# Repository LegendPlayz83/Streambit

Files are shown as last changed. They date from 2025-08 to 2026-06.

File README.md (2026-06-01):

# Streambit

This is my 65% Keyboard, which I made from scratch with some help. It is named Streambit.<br>

Physical view:


Full-assembled

<br>
A special thanks to Kai, Anay, Mohid, and Souptik, and a big thanks to Alex, who is helping me improve my projects. 💓

# Inspiration
I've always wanted to build a keyboard, and Blueprint gave me the perfect opportunity for this

# Challenges
This was the first time using some new libraries. There were not many big issues, just usage problems which were resolved on Slack <a href="hackclub.slack.com/archives/C0948RT0C1M">Grounded</a>.
<br>
It was sad getting your keyboard rejected. The spirit of getting it approved on the first try is something else.

# Specifications

# Keyboard PCB – Bill of Materials (BOM)

| Component | Quantity | Unit Price | Total |
|---|---|---|---|
| [**TTC Silent Red V3 MX Mechanical Switches**](https://stackskb.com/store/ttc-silent-red-v3-switch/) | 64 | $0.45 | $28.80 |
| [**1N4148 Switching Diodes**](https://amzn.in/d/02ax8rq9) | 100 | $0.0206 | $2.06 |
| [**Cherry MX Plate Mount Stabilizers (2U)**](https://stackskb.com/store/genuine-cherry-mx-plate-mount-stabilizers-2u/) | 4 | $1.30 | $5.20 |
| [**Durock Smokey Screw-In Stabilizers V2 (4+1 w/ 6.25u spacebar)**](https://stackskb.com/store/durock-smokey-screw-in-stabilizers-v2/) | 1 | $18.58 | $18.58 |
| [**EC11 Rotary Encoder with Switch**](https://www.flyrobo.in/15mm-ec11-rotary-encoder-with-switch-digital-potentiometer) | 1 | $0.68 | $0.68 |
| **SK6812 MINI LEDs** | 4  | $2.95 | $2.95 |
| [**Raspberry Pi Zero W**](https://amzn.in/d/4E8fnHk) | 1 | $10.00 | $10.00 |
| [**Iceberg Japanese XDA PBT Keycaps**](https://curiositycaps.in/products/iceberg-japanese-xda-pbt-keycaps-1) | 1 | $25.00 | $25.00 |
| [**Custom PCB (JLCPCB)**](https://jlcpcb.com/) | 1 | $48.86 | $48.86 |
| **Case (From printing-legion)** | 1 | $5.00 | $5.00 |
---

**Grand Total: $147.13**<br>
Others:
<ul>
<li>KMK Firmware
<li>Top Case.stl
</ul>

<h3>Schematic-</h3>
Screenshot 2025-07-25 at 6 26 07 PM

<h3>PCB</h3>
pcb

<h3>PCB in 3D view</h3>
3d view

<h3>Case</h3>
case
psst: two keys were placed wrongly dont mind :)

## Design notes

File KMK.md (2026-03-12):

## Flashing nd Configuring the Keyboard

Steps to install the firmware and configure the keyboard:-

### 1. Downloading the Repository
Download or clone this repository to your computer.
https://github.com/LegendPlayz83/Streambit.git

### 2. Enter Boot Mode on the Pico
1. Unplug the Raspberry Pi Pico from your computer.
2. Hold down the **BOOTSEL** button on the Pico.
3. While holding the button, plug the Pico into your computer using a USB cable.
4. The computer will detect a new drive, namely **RPI-RP2**.

### 3. Flash the Firmware
1. Download the `.uf2` firmware file from this repo.
2. Drag and drop the file onto the **RPI-RP2** drive.

Once the file finishes copying, the Pico will reboot automatically.

### 4. Install KMK Files
After rebooting, the Pico will appear as a new drive (usually named **CIRCUITPY**).

Copy the KMK firmware files from this repository onto the Pico if they are not already included.

### 5. Configure the Keymap
The keyboard layout can be customised in the `code.py` (or `keymap.py`) file.

Open the file in a text editor nd edit the keymap section to match the layout you want.  
After saving the file, the keyboard will automatically reload with the new configuration.

### 6. Test the Keyboard
Unplug and reconnect the keyboard, open a text editor, and press some keys to make sure everything works.

<h1>KABOOM!</h1>
ITS DONE!!!

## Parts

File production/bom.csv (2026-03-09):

Name | Quantity | Cost | Link
TTC Silent Red V3 | 70 | $28.80 | https://stackskb.com/store/ttc-silent-red-v3-switch/
Durock Smokey Screw-In Stabilizers V2 (4+1 w/ 6.25u spacebar) | 1 | $18.58 | https://stackskb.com/store/durock-smokey-screw-in-stabilizers-v2/
EC11 Rotary Encoder with Switch | 1 | $0.68 | https://www.flyrobo.in/15mm-ec11-rotary-encoder-with-switch-digital-potentiometer
Cherry MX Plate Mount Stabilizers (2U) | 4 | $5.20 | https://stackskb.com/store/genuine-cherry-mx-plate-mount-stabilizers-2u/
Iceberg Japanese XDA PBT Keycaps | 1 | $25.00 | https://curiositycaps.in/products/iceberg-japanese-xda-pbt-keycaps-1
Diode 1N4148 Through - Hole | 100 | $2.06 | https://www.amazon.in/dp/B084ZP5BJ3?ref_=cm_sw_r_cp_ud_dp_YPW3WFYTE31QA18570D1&_encoding=UTF8&psc=1
SK6812 LEDs | 4 | $2.95 | Local store
PCB - (Black Color) | 5 | $48.86 | https://jlcpcb.com/
Raspberry Pi Pico | 1 | $10.00 | https://amzn.in/d/4E8fnHk
Case- top,mid,bot | 1 | $5.00 | Printing Legion transport charges

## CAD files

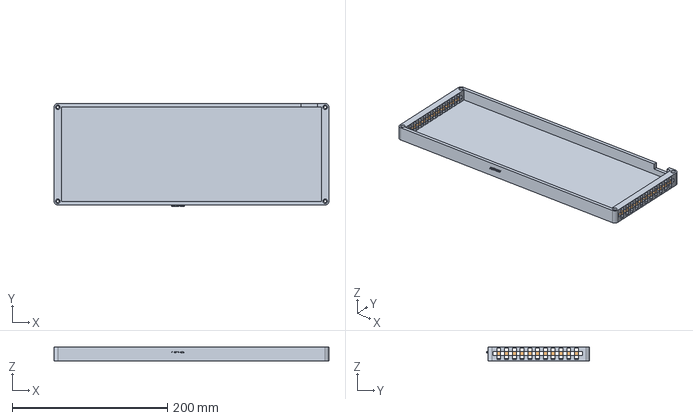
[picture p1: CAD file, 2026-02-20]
cad/Streambit Case.step
354.0 x 133.0 x 18.0 mm

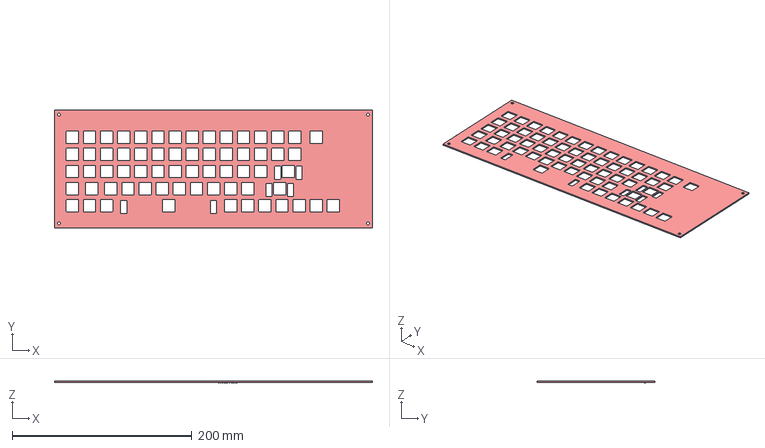
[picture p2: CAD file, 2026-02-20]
cad/Bitstream cover.step
354.0 x 131.0 x 1.70 mm

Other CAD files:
production/Streambit_Top.stl

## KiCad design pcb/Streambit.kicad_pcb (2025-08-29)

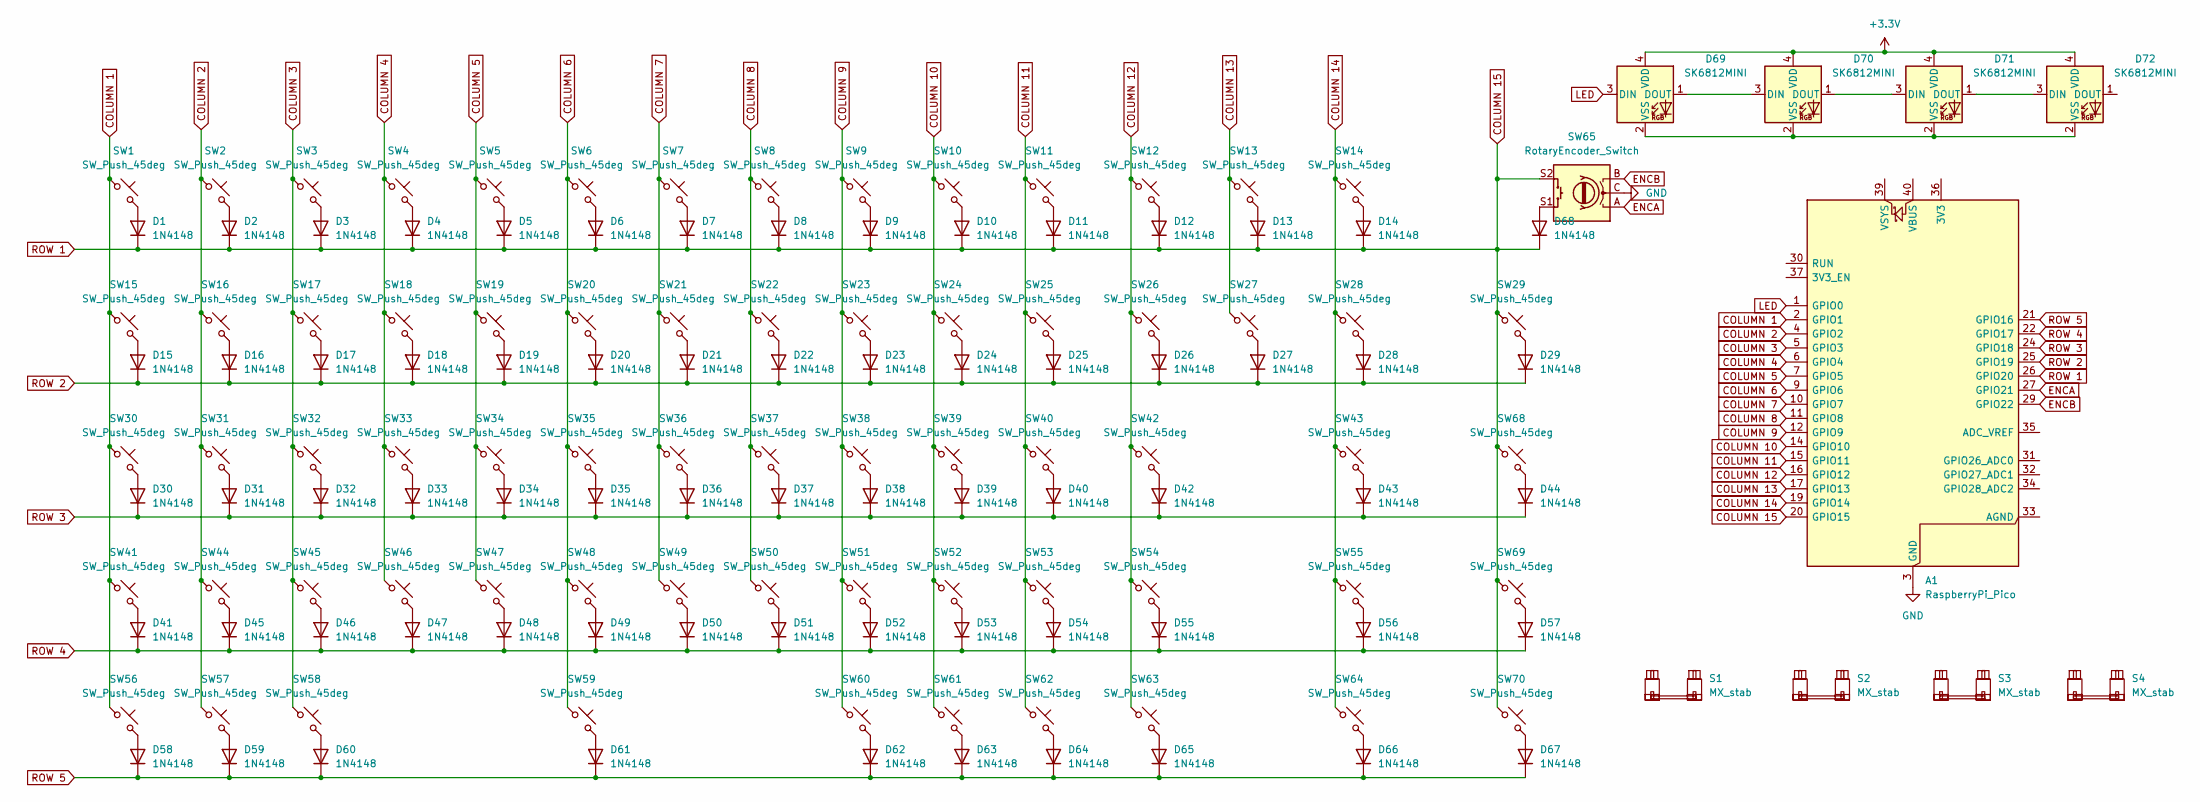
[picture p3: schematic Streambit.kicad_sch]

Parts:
A1: RaspberryPi_Pico; RaspberryPi_Pico_SMD_HandSolder
D1, D2, D3, D4, D5, D6, D7, D8, D9, D10, D11, D12, D13, D14, D15, D16, D17, D18, D19, D20, D21, D22, D23, D24, D25, D26, D27, D28, D29, D30, D31, D32, D33, D34, D35, D36, D37, D38, D39, D40, D41, D42, D43, D44, D45, D46, D47, D48, D49, D50, D51, D52, D53, D54, D55, D56, D57, D58, D59, D60, D61, D62, D63, D64, D65, D66, D67, D68: 1N4148; D_DO-35_SOD27_P7.62mm_Horizontal
D69, D70, D71, D72: SK6812MINI; LED_SK6812MINI_PLCC4_3.5x3.5mm_P1.75mm
S1, S2, S3: MX_stab; Stabilizer_Cherry_MX_2.00u
S4: MX_stab; Stabilizer_Cherry_MX_6.25u
SW1, SW2, SW3, SW4, SW5, SW6, SW7, SW8, SW9, SW10, SW11, SW12, SW13, SW14, SW15, SW16, SW17, SW18, SW19, SW20, SW21, SW22, SW23, SW24, SW25, SW26, SW27, SW28, SW29, SW30, SW31, SW32, SW33, SW34, SW35, SW36, SW37, SW38, SW39, SW40, SW41, SW42, SW43, SW44, SW45, SW46, SW47, SW48, SW49, SW50, SW51, SW52, SW53, SW54, SW55, SW56, SW57, SW58, SW59, SW60, SW61, SW62, SW63, SW64, SW68, SW69, SW70: SW_Push_45deg; SW_Cherry_MX_1.00u_PCB
SW65: RotaryEncoder_Switch; RotaryEncoder_Alps_EC11E-Switch_Vertical_H20mm

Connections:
+3.3V: D69.4 (VDD), D70.4 (VDD), D71.4 (VDD), D72.4 (VDD)
COLUMN 1: A1.2 (GPIO1), SW1.1, SW15.1, SW30.1, SW41.1, SW56.1
COLUMN 2: A1.4 (GPIO2), SW2.1, SW16.1, SW31.1, SW44.1, SW57.1
COLUMN 3: A1.5 (GPIO3), SW3.1, SW17.1, SW32.1, SW45.1, SW58.1
COLUMN 4: A1.6 (GPIO4), SW4.1, SW18.1, SW33.1, SW46.1
COLUMN 5: A1.7 (GPIO5), SW5.1, SW19.1, SW34.1, SW47.1
COLUMN 6: A1.9 (GPIO6), SW6.1, SW20.1, SW35.1, SW48.1, SW59.1
COLUMN 7: A1.10 (GPIO7), SW7.1, SW21.1, SW36.1, SW49.1
COLUMN 8: A1.11 (GPIO8), SW8.1, SW22.1, SW37.1, SW50.1
COLUMN 9: A1.12 (GPIO9), SW9.1, SW23.1, SW38.1, SW51.1, SW60.1
COLUMN 10: A1.14 (GPIO10), SW10.1, SW24.1, SW39.1, SW52.1, SW61.1
COLUMN 11: A1.15 (GPIO11), SW11.1, SW25.1, SW40.1, SW53.1, SW62.1
COLUMN 12: A1.16 (GPIO12)
COLUMN 13: A1.17 (GPIO13), SW13.1, SW27.1
COLUMN 14: A1.19 (GPIO14), SW14.1, SW28.1, SW43.1, SW55.1, SW64.1
COLUMN 15: A1.20 (GPIO15), A1.26 (GPIO20), D1.1 (K), D2.1 (K), D3.1 (K), D4.1 (K), D5.1 (K), D6.1 (K), D7.1 (K), D8.1 (K), D9.1 (K), D10.1 (K), D11.1 (K), D12.1 (K), D13.1 (K), D14.1 (K), D68.1 (K), SW29.1, SW65.S2, SW68.1, SW69.1, SW70.1
COLUMN 12: SW12.1, SW26.1, SW42.1, SW54.1, SW63.1
ENCA: A1.27 (GPIO21), SW65.A
ENCB: A1.29 (GPIO22), SW65.B
GND: A1.3 (GND), A1.8 (GND), A1.13 (GND), A1.18 (GND), A1.23 (GND), A1.28 (GND), A1.38 (GND), SW65.C
LED: A1.1 (GPIO0), D69.3 (DIN)
unnamed: D1.2 (A), SW1.2
unnamed: D2.2 (A), SW2.2
unnamed: D3.2 (A), SW3.2
unnamed: D4.2 (A), SW4.2
unnamed: D5.2 (A), SW5.2
unnamed: D6.2 (A), SW6.2
unnamed: D7.2 (A), SW7.2
unnamed: D8.2 (A), SW8.2
unnamed: D9.2 (A), SW9.2
unnamed: D10.2 (A), SW10.2
unnamed: D11.2 (A), SW11.2
unnamed: D12.2 (A), SW12.2
unnamed: D13.2 (A), SW13.2
unnamed: D14.2 (A), SW14.2
unnamed: D15.2 (A), SW15.2
unnamed: D16.2 (A), SW16.2
unnamed: D17.2 (A), SW17.2
unnamed: D18.2 (A), SW18.2
unnamed: D19.2 (A), SW19.2
unnamed: D20.2 (A), SW20.2
unnamed: D21.2 (A), SW21.2
unnamed: D22.2 (A), SW22.2
unnamed: D23.2 (A), SW23.2
unnamed: D24.2 (A), SW24.2
unnamed: D25.2 (A), SW25.2
unnamed: D26.2 (A), SW26.2
unnamed: D27.2 (A), SW27.2
unnamed: D28.2 (A), SW28.2
unnamed: D29.2 (A), SW29.2
unnamed: D30.2 (A), SW30.2
unnamed: D31.2 (A), SW31.2
unnamed: D32.2 (A), SW32.2
unnamed: D33.2 (A), SW33.2
unnamed: D34.2 (A), SW34.2
unnamed: D35.2 (A), SW35.2
unnamed: D36.2 (A), SW36.2
unnamed: D37.2 (A), SW37.2
unnamed: D38.2 (A), SW38.2
unnamed: D39.2 (A), SW39.2
unnamed: D40.2 (A), SW40.2
unnamed: D41.2 (A), SW41.2
unnamed: D42.2 (A), SW42.2
unnamed: D43.2 (A), SW43.2
unnamed: D44.2 (A), SW68.2
unnamed: D45.2 (A), SW44.2
unnamed: D46.2 (A), SW45.2
unnamed: D47.2 (A), SW46.2
unnamed: D48.2 (A), SW47.2
unnamed: D49.2 (A), SW48.2
unnamed: D50.2 (A), SW49.2
unnamed: D51.2 (A), SW50.2
unnamed: D52.2 (A), SW51.2
unnamed: D53.2 (A), SW52.2
unnamed: D54.2 (A), SW53.2
unnamed: D55.2 (A), SW54.2
unnamed: D56.2 (A), SW55.2
unnamed: D57.2 (A), SW69.2
unnamed: D58.2 (A), SW56.2
unnamed: D59.2 (A), SW57.2
unnamed: D60.2 (A), SW58.2
unnamed: D61.2 (A), SW59.2
unnamed: D62.2 (A), SW60.2
unnamed: D63.2 (A), SW61.2
unnamed: D64.2 (A), SW62.2
unnamed: D65.2 (A), SW63.2
unnamed: D66.2 (A), SW64.2
unnamed: D67.2 (A), SW70.2
unnamed: D68.2 (A), SW65.S1
unnamed: D69.1 (DOUT), D70.3 (DIN)
unnamed: D69.2 (VSS), D70.2 (VSS), D71.2 (VSS), D72.2 (VSS)
unnamed: D70.1 (DOUT), D71.3 (DIN)
unnamed: D71.1 (DOUT), D72.3 (DIN)
ROW 2: A1.25 (GPIO19), D15.1 (K), D16.1 (K), D17.1 (K), D18.1 (K), D19.1 (K), D20.1 (K), D21.1 (K), D22.1 (K), D23.1 (K), D24.1 (K), D25.1 (K), D26.1 (K), D27.1 (K), D28.1 (K), D29.1 (K)
ROW 3: A1.24 (GPIO18), D30.1 (K), D31.1 (K), D32.1 (K), D33.1 (K), D34.1 (K), D35.1 (K), D36.1 (K), D37.1 (K), D38.1 (K), D39.1 (K), D40.1 (K), D42.1 (K), D43.1 (K), D44.1 (K)
ROW 4: A1.22 (GPIO17), D41.1 (K), D45.1 (K), D46.1 (K), D47.1 (K), D48.1 (K), D49.1 (K), D50.1 (K), D51.1 (K), D52.1 (K), D53.1 (K), D54.1 (K), D55.1 (K), D56.1 (K), D57.1 (K)
ROW 5: A1.21 (GPIO16), D58.1 (K), D59.1 (K), D60.1 (K), D61.1 (K), D62.1 (K), D63.1 (K), D64.1 (K), D65.1 (K), D66.1 (K), D67.1 (K)

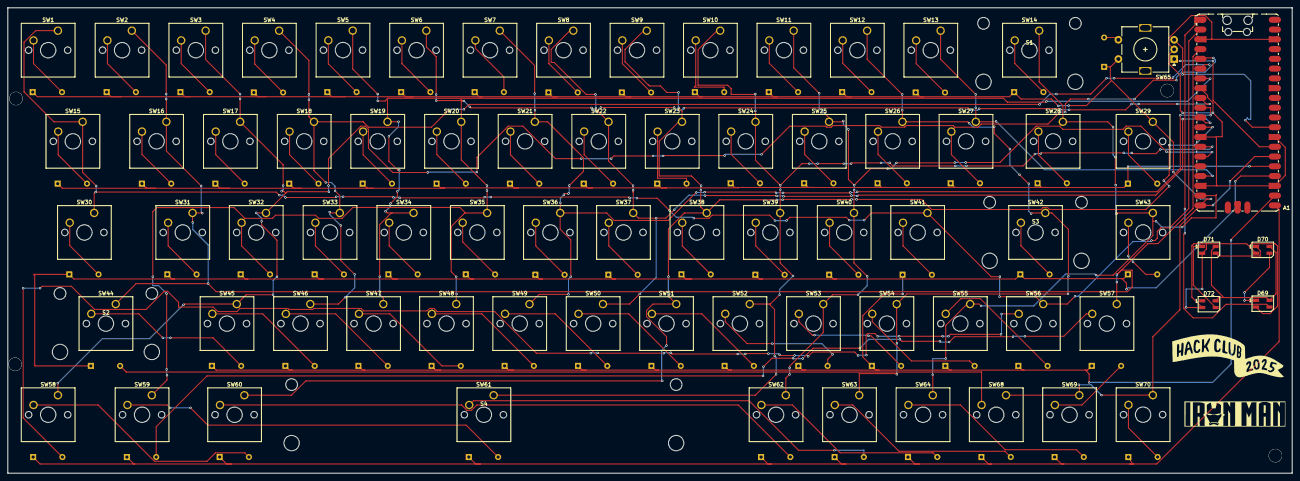
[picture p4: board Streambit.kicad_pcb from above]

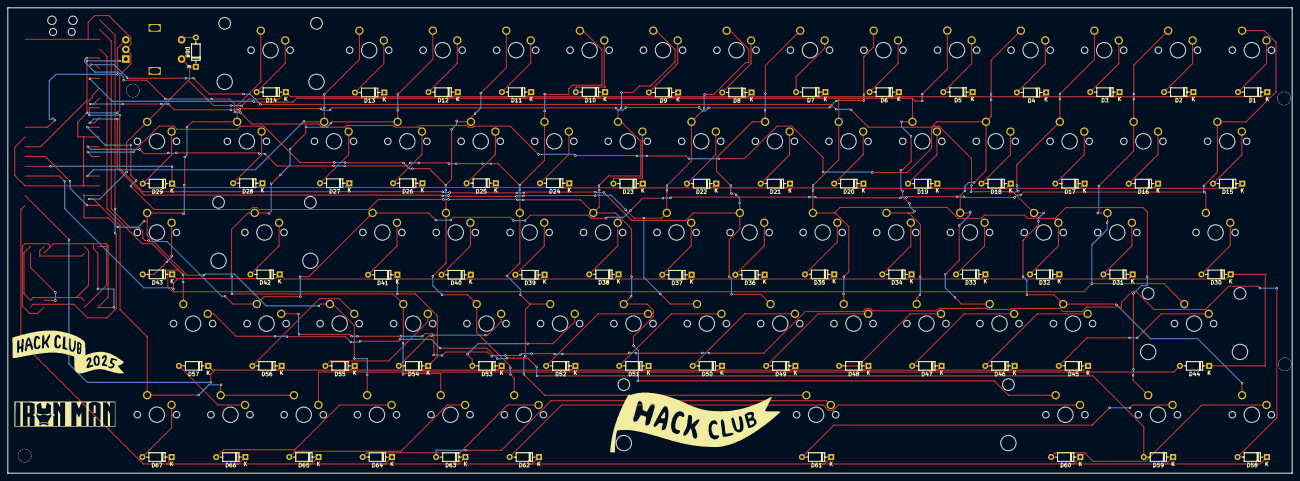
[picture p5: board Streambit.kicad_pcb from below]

Board: 2 copper layers, 334.0 x 121.0 mm, 145 parts (68 on the bottom side), 96 nets.

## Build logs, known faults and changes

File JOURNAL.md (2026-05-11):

<h1>Journal</h1>
Title: "Streambit"<br>
Author: "Aditya Roy(U04AKUFC402)"<br>
Description: "A 65% Keyboard made from scratch"<br>
Created On: "15/8/2025"<br>

I started from a layout for the keyboard, looking at designs like 100%, 85%, 70%, 65% and 65% looked the best to me.<br>
So, with some guides, I started with the schematic in KiCad 9.0.<br><br>

After placing everything systematically, it looked like this!

Screenshot 2025-07-23 at 6 18 33 PM
Time Spent: 30 mins<br>
<b>**Total time: 30 mins**<b>

<h3>Wiring Time!</h3>
After wiring every component in the schematic, it came out like this
Screenshot 2025-07-25 at 6 26 07 PM
Time spent: 45 mins<br>
<b>**Total time: 1hr 15mins**</b>

<h2>Placing the components on the pcb</h2>
After turning the schematic into a PCB, I started placing the components on the PCB in order of the 65% keyboard I planned to make. Did not remember to get a screenshot of the process
Time spent: 1hr 30mins<br>
<b>**Total time: 2hr 45mins**</b>

<h2>Time to Route everything!</h2>
After finally placing the components with the correct spacing and order, I had to do the routings. It was a very long process and indeed took a very long time. I had to adjust the routings accordingly to be able to place vias, turn the layer while routing, leave space for the routes to change layers, and more.
<br>
Routing progress 


Final Routed PCB<br>
<h6>Added Silkscreen also!</h6>
done
Time spent: 4hr 15mins<br>
<b>**Total time: 7hours**</b>

<h2>Case Designing Time!</h2>
For this case, I decided to use only a bottom case as an open PCB looks very beautiful. 
<h4>Creating Sketch!</h4>
Screenshot 2025-07-28 at 8 11 55 PM

<h4>Adding holes for mount</h4>
Screenshot 2025-07-29 at 4 28 10 PM

After extruding the PCB, I made some designs on the sides of the case.<br>
Photo:<br>
Screenshot 2025-07-29 at 4 33 41 PM

Video:<br>

https://github.com/user-attachments/assets/81f87b0e-f5fe-4575-91ca-c8a29a3c5382

<h3>Branding the Case!</h3><br>
Screenshot 2025-07-29 at 6 12 16 PM

<h2>Case is Done!</h2><br>
Screenshot 2025-08-25 at 7 02 32 PM
Time taken: 3hours
<b>**Total time: 10 hours**</b>

<h5>Gotta assemble everything physically now</h5><br>
Screenshot 2025-08-26 at 4 48 28 PM

<h3>Physical assembly time!</h3>
After getting all the components, I started by placing the diodes in place. In this, I had to bend each side of the diode to sit exactly in the centre of the logo, else it would have gone left or right while soldering.
Diodes place
Time taken: 2hours
<b>Total Time: 12 hours</b>

<h4>Soldeing all diodes in place</h4>
After the placement session of the diodes was done, I had to solder them to the PCB and cut their long wires left. 
In this, I had to ensure that the diodes were placed correctly, else the resultant solder would have come out badly. 
Soldered results:<br>
Front
Diodes front
Back
Diodes back
Time taken: 1.5 hour
<b>Total time: 13.5 hours</b>

<h4>Soldering keys and joining stabs</h4>
After placing and soldering all of the 1N4148 diodes, I now had to solder my Cherry MX keys to the PCB. It was soooo fun, and it consumed 4 meters of soldering wire
Final look:<br>

Time taken: 3 hours
<b>Total time: 16.5 hours</b>

<h4>Solder Ras pi Pico</h4>
After being done with the 1N4148 diodes and Cherry MX switches, it was time to solder the last thing, which was the Raspberry Pi Pico to the PCB. Remember, the Ras pi pico was SMD, and I used a soldering iron for this job.
Final look:<br>

Time taken: 0.5 hours
<b>Total time: 17 hours</b>

<h3>Firmware time!!!</h3>
After being done with the soldering and things, I now had to upload the code to the Pico. I made many versions of the code coz the keys acted weird, rows and columns were wrongly arranged, and there were many bugs with the code.


Time taken: 4 hours<br>
<b>Total time: 21 hours</b>
psst: two keys were placed wrongly dont mind :)

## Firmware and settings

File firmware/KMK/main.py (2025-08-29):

import board
from kmk.kmk_keyboard import KMKKeyboard
from kmk.keys import KC
from kmk.modules.layers import Layers
from kmk.modules.encoder import EncoderHandler
from kmk.scanners import DiodeOrientation
from kmk.extensions.peg_rgb import RGB, AnimationModes

keyboard = KMKKeyboard()

# Diode direction
keyboard.diode_orientation = DiodeOrientation.COL2ROW

# Matrix pins
keyboard.col_pins = (
    board.GP0, board.GP1, board.GP2, board.GP3, board.GP4,
    board.GP5, board.GP6, board.GP7, board.GP8, board.GP9,
    board.GP10, board.GP11, board.GP12, board.GP13, board.GP14, board.GP15
)

keyboard.row_pins = (
    board.GP16, board.GP17, board.GP18, board.GP19, board.GP20
)

# Encoder setup
encoder = EncoderHandler()
encoder.pins = ((board.GP27, board.GP28, board.GP26),)
encoder.map = (((KC.VOLD, KC.VOLU, KC.MUTE),),)
keyboard.modules.append(encoder)

# Layers support
layers = Layers()
keyboard.modules.append(layers)

# RGB Setup (SK6812)
rgb = RGB(
    pixel_pin=board.GP22,
    num_pixels=4,  # You have 4 SK6812MINI
    hue_default=180,
    sat_default=255,
    val_default=64,
    animation_mode=AnimationModes.SOLID,
)
keyboard.extensions.append(rgb)

# Keymap (trimmed for brevity; same as before)
keyboard.keymap = [
    [
        KC.ESC, KC.N1, KC.N2, KC.N3, KC.N4, KC.N5, KC.N6, KC.N7, KC.N8, KC.N9, KC.N0, KC.MINS, KC.EQL, KC.BSPC, KC.NO, KC.NO,
        KC.TAB, KC.Q, KC.W, KC.E, KC.R, KC.T, KC.Y, KC.U, KC.I, KC.O, KC.P, KC.LBRC, KC.RBRC, KC.BSLS, KC.NO, KC.NO,
        KC.CAPS, KC.A, KC.S, KC.D, KC.F, KC.G, KC.H, KC.J, KC.K, KC.L, KC.SCLN, KC.QUOT, KC.ENTER, KC.NO, KC.NO, KC.NO,
        KC.LSFT, KC.Z, KC.X, KC.C, KC.V, KC.B, KC.N, KC.M, KC.COMM, KC.DOT, KC.SLSH, KC.RSFT, KC.NO, KC.NO, KC.NO, KC.NO,
        KC.LCTL, KC.LGUI, KC.LALT, KC.SPC, KC.SPC, KC.RALT, KC.FN0, KC.RCTL, KC.LEFT, KC.DOWN, KC.UP, KC.RIGHT, KC.NO, KC.NO, KC.NO, KC.NO
    ]
]

if __name__ == '__main__':
    keyboard.go()

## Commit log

2026-02-19 Delete BOM.md
    Rather adding bom.csv
2026-02-20 Rename Bitsteam Case.step to Streambit Case.step
    [Streambit Case.step]
2026-03-09 Revise README with BOM and cost details
    Updated the README to include a detailed Bill of Materials (BOM) and cost summary for the keyboard project.
2026-03-12 Changed images
    Changed images after corrections and making a new case
